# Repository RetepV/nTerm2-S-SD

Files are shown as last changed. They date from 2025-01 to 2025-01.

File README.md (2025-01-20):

# nTerm2-S-SD
My rendition of the uTerm2-S. In SMD, but easily solderable. In a slightly more usable form. As extra, it can switch between normal and cross (null-modem) in software.

This is a rendition of the nTerm2-S with extra PSRAM, a few extra I/O lines, and an SD card slot.

It is based on the FABGL library from Fabrizio Di Vittori.

THIS IS A WORK IN PROGESS! I.E. UNLESS STATED AS WORKING, IT DOES NOT WORK!

This design is available under GPL License V3. This means that I DO NOT release it for commercial use, unless with my explicit written and signed consent. Please contact me if you have commercial questions.

uTerm2-S: https://hackaday.io/project/181583-uterm2-s-a-multi-emulation-color-rs232-terminal
fabgl: http://www.fabglib.org/, https://github.com/fdivitto/FabGL

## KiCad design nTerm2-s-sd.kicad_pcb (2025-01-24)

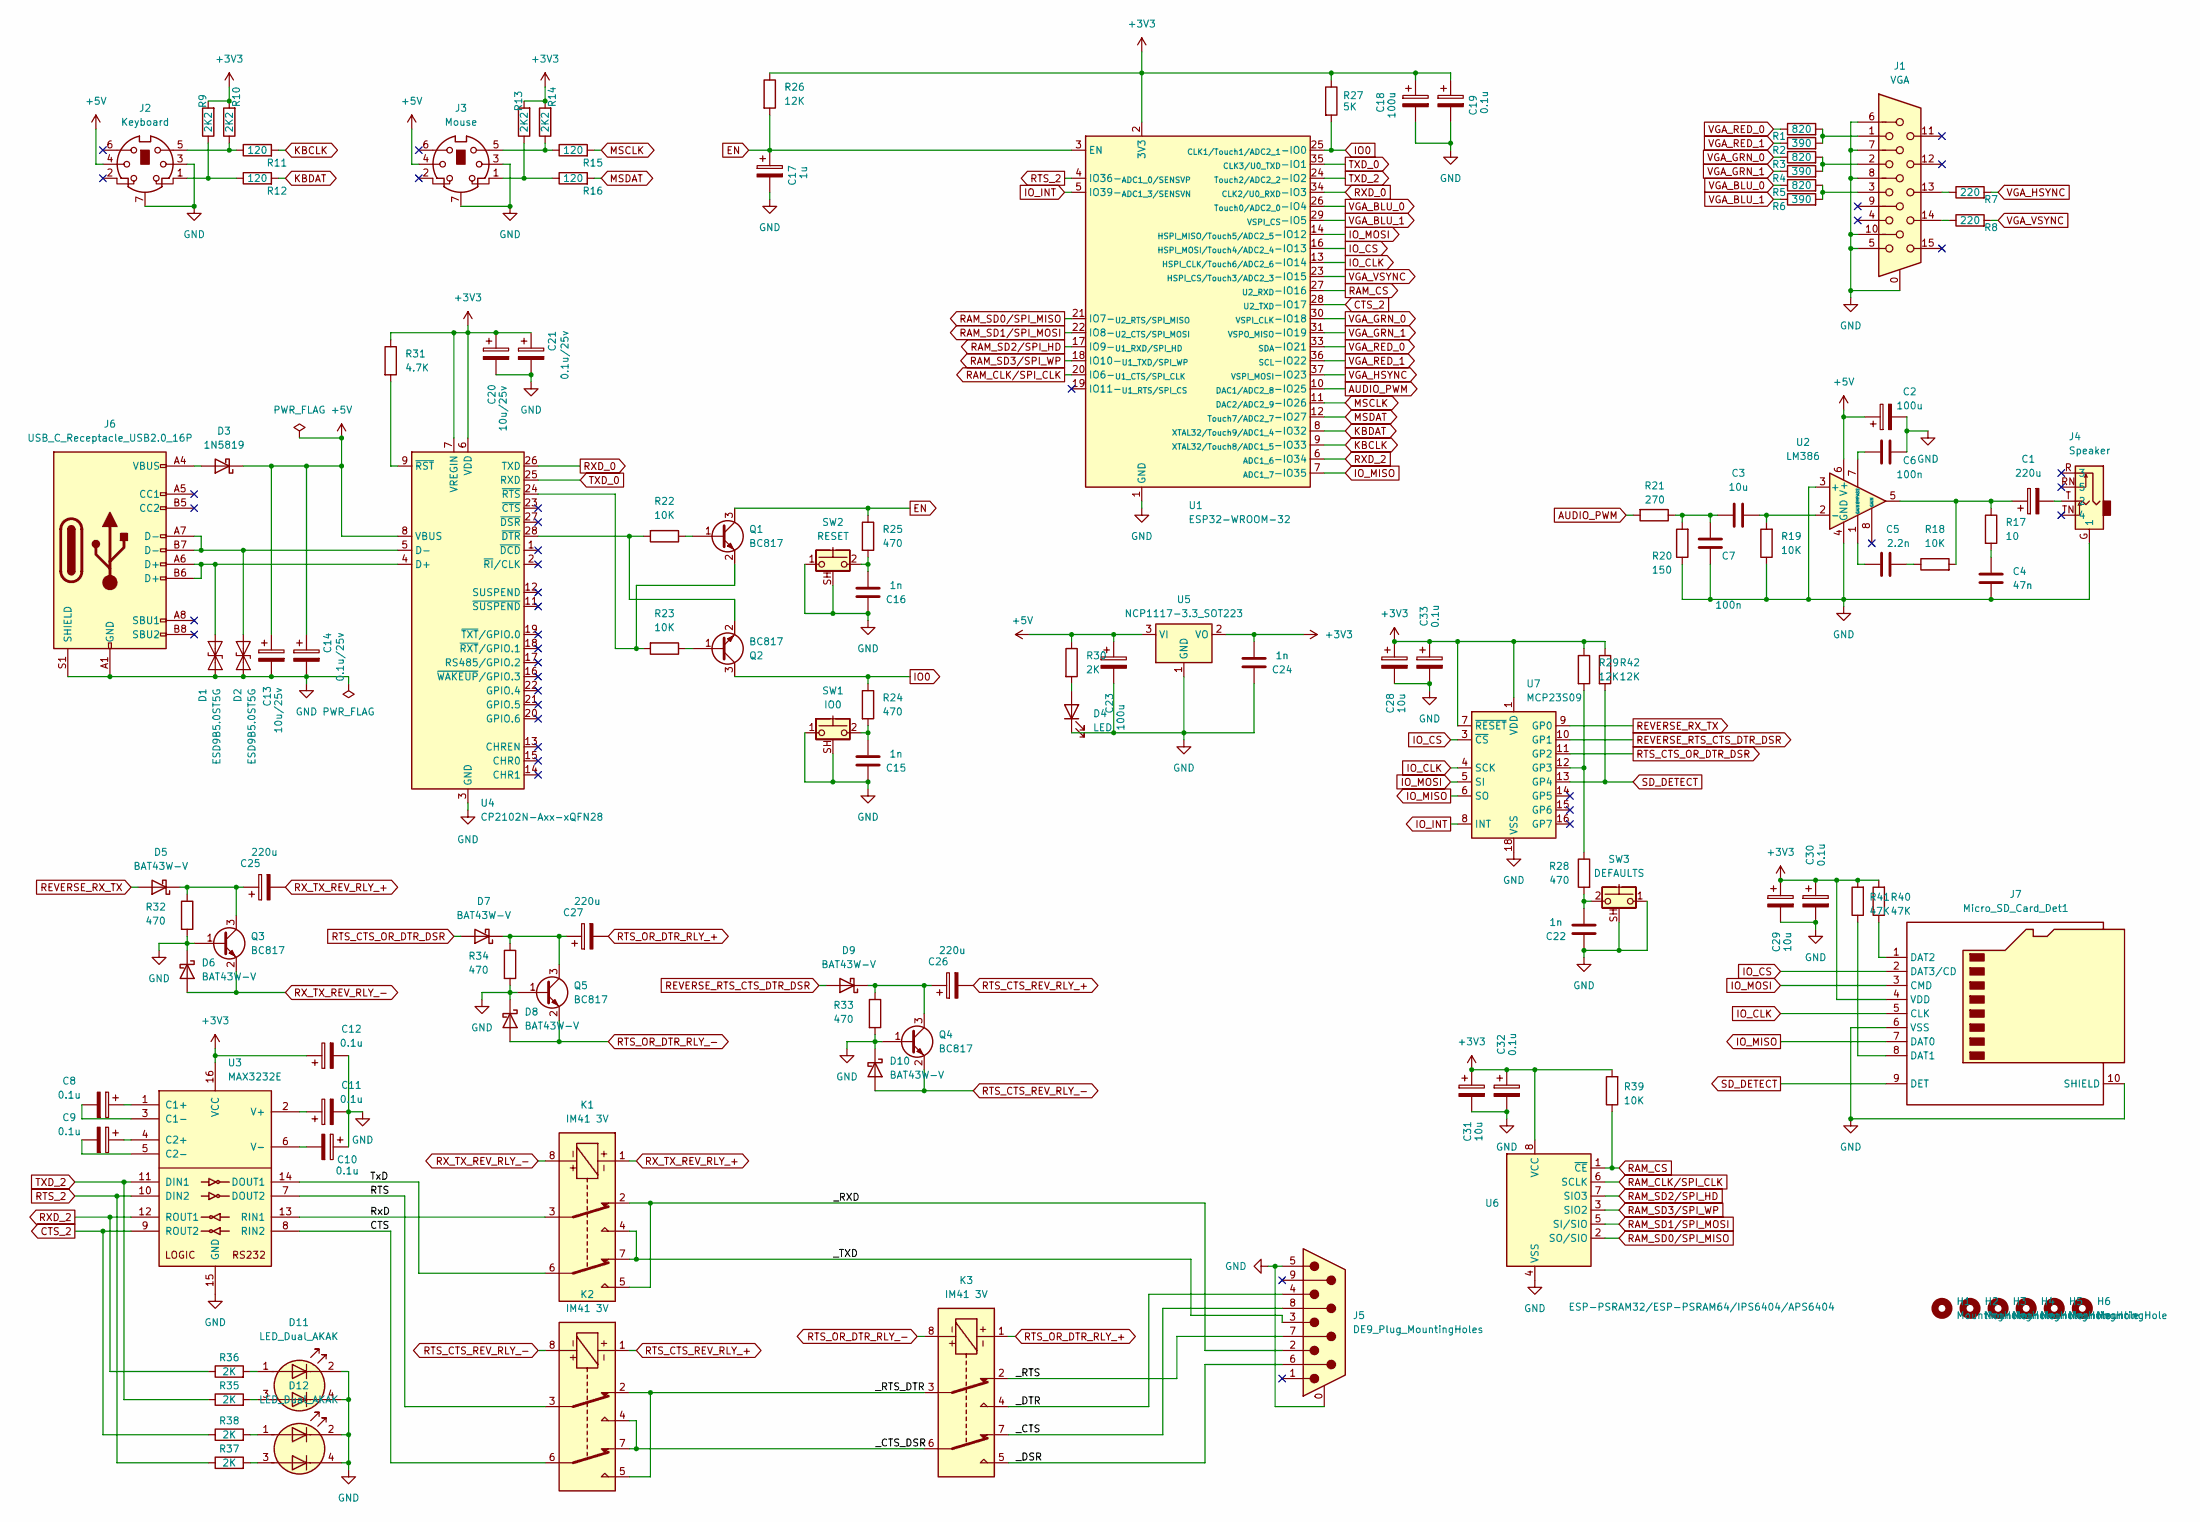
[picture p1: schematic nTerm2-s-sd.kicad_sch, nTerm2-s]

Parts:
C1: 220u; CP_Elec_6.3x7.7
C2: 100u; CP_Elec_6.3x7.7
C3: 10u; C_0805_2012Metric_Pad1.18x1.45mm_HandSolder
C4: 47n; C_0603_1608Metric_Pad1.08x0.95mm_HandSolder
C5: 2.2n; C_0603_1608Metric_Pad1.08x0.95mm_HandSolder
C6, C7: 100n; C_0603_1608Metric_Pad1.08x0.95mm_HandSolder
C8, C9, C10, C11, C12, C19, C30, C32, C33: 0.1u; CP_EIA-3216-18_Kemet-A_Pad1.58x1.35mm_HandSolder
C13, C20: 10u/25v; CP_EIA-3216-18_Kemet-A_Pad1.58x1.35mm_HandSolder
C14, C21: 0.1u/25v; CP_EIA-3216-18_Kemet-A_Pad1.58x1.35mm_HandSolder
C15, C16, C22, C24: 1n; C_0603_1608Metric_Pad1.08x0.95mm_HandSolder
C17: 1u; CP_EIA-3216-18_Kemet-A_Pad1.58x1.35mm_HandSolder
C18, C23: 100u; CP_EIA-3216-18_Kemet-A_Pad1.58x1.35mm_HandSolder
C25, C26, C27: 220u; CP_EIA-3216-18_Kemet-A_Pad1.58x1.35mm_HandSolder
C28, C29, C31: 10u; CP_EIA-3216-18_Kemet-A_Pad1.58x1.35mm_HandSolder
D1, D2: ESD9B5.0ST5G; D_SOD-923
D3: 1N5819; Nexperia_CFP3_SOD-123W
D4: LED; DIALIGHT_LED_3MM_SINGLE
D5, D6, D7, D8, D9, D10: BAT43W-V; D_SOD-123
D11, D12: LED_Dual_AKAK; DIALIGHT_LED_3MM_DOUBLE
H1, H2, H3, H4, H5, H6: MountingHole; MountingHole_3.2mm_M3
J1: VGA; DSUB-15-HD_Female_Horizontal_P2.29x1.98mm_EdgePinOffset8.35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
J2: Keyboard; Connector_Mini-DIN_Female_6Pin_2rows
J3: Mouse; Connector_Mini-DIN_Female_6Pin_2rows
J4: Speaker; Jack_3.5mm_Ledino_KB3SPRS_Horizontal
J5: DE9_Plug_MountingHoles; DSUB-9_Male_Horizontal_P2.77x2.84mm_EdgePinOffset4.94mm_Hou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
J6: USB_C_Receptacle_USB2.0_16P; USB_C_Receptacle_Molex_213716-0001
J7: Micro_SD_Card_Det1; GCT-MEM2055-00-190-01-A
K1, K2, K3: IM41 3V; Relay_DPDT_AXICOM_IMSeries_JLeg
Q1, Q2, Q3, Q4, Q5: BC817; SOT-23
R1, R3, R5: 820; R_0603_1608Metric_Pad0.98x0.95mm_HandSolder
R2, R4, R6: 390; R_0603_1608Metric_Pad0.98x0.95mm_HandSolder
R7, R8: 220; R_0603_1608Metric_Pad0.98x0.95mm_HandSolder
R9, R10, R13, R14: 2K2; R_0603_1608Metric_Pad0.98x0.95mm_HandSolder
R11, R12, R15, R16: 120; R_0603_1608Metric_Pad0.98x0.95mm_HandSolder
R17: 10; R_0603_1608Metric_Pad0.98x0.95mm_HandSolder
R18, R19, R22, R23, R39: 10K; R_0603_1608Metric_Pad0.98x0.95mm_HandSolder
R20: 150; R_0603_1608Metric_Pad0.98x0.95mm_HandSolder
R21: 270; R_0603_1608Metric_Pad0.98x0.95mm_HandSolder
R24, R25, R28, R32, R33, R34: 470; R_0603_1608Metric_Pad0.98x0.95mm_HandSolder
R26, R29, R42: 12K; R_0603_1608Metric_Pad0.98x0.95mm_HandSolder
R27: 5K; R_0603_1608Metric_Pad0.98x0.95mm_HandSolder
R30, R35, R36, R37, R38: 2K; R_0603_1608Metric_Pad0.98x0.95mm_HandSolder
R31: 4.7K; R_0603_1608Metric_Pad0.98x0.95mm_HandSolder
R40, R41: 47K; R_0603_1608Metric_Pad0.98x0.95mm_HandSolder
SW1: IO0; SW_Tactile_SPST_Angled_PTS645Vx58-2LFS
SW2: RESET; SW_Tactile_SPST_Angled_PTS645Vx58-2LFS
SW3: DEFAULTS; SW_Tactile_SPST_Angled_PTS645Vx58-2LFS
U1: ESP32-WROOM-32
U2: LM386; SOIC-8_3.9x4.9mm_P1.27mm
U3: MAX3232E; SOIC-16_3.9x9.9mm_P1.27mm
U4: CP2102N-Axx-xQFN28; QFN-28-1EP_5x5mm_P0.5mm_EP3.35x3.35mm
U5: NCP1117-3.3_SOT223; SOT-223-3_TabPin2
U6: ESP-PSRAM32/ESP-PSRAM64/IPS6404/APS6404; SOIC-8_3.9x4.9mm_P1.27mm
U7: MCP23S09; SOIC-18W_7.5x11.6mm_P1.27mm

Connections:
+3V3: C12.1, C18.1, C19.1, C20.1, C21.1, C24.1, C28.1, C29.1, C30.1, C31.1, C32.1, C33.1, J7.4 (VDD), R9.2, R10.2, R13.2, R14.2, R26.1, R27.1, R29.1, R31.1, R39.2, R40.2, R41.2, R42.1, U1.2 (3V3), U3.16 (VCC), U4.6 (VDD), U4.7 (VREGIN), U5.2 (VO), U6.8 (VCC), U7.1 (VDD), U7.7 (~RESET)
+5V: C2.1, C13.1, C14.1, C23.1, D3.1 (K), J2.4, J3.4, R30.1, U2.6 (V+), U4.8 (VBUS), U5.3 (VI)
/CTS: K2.6, U3.8 (RIN2)
/RTS: K2.3, U3.7 (DOUT2)
/RxD: K1.3, U3.13 (RIN1)
/TxD: K1.6, U3.14 (DOUT1)
/_CTS: J5.8, K3.7
/_CTS_DSR: K2.4, K2.7, K3.6
/_DSR: J5.6, K3.5
/_DTR: J5.4, K3.4
/_RTS: J5.7, K3.2
/_RTS_DTR: K2.2, K2.5, K3.3
/_RXD: J5.2, K1.2, K1.5
/_TXD: J5.3, K1.4, K1.7
AUDIO_PWM: R21.2, U1.10 (_{DAC1/ADC2_8}-IO25)
CTS_2: R38.1, U1.28 (_{U2_TXD}-IO17), U3.9 (ROUT2)
EN: C17.1, Q1.3 (C), R25.1, R26.2, U1.3 (EN)
GND: C2.2, C4.2, C6.2, C7.1, C10.1, C11.2, C12.2, C13.2, C14.2, C15.2, C16.2, C17.2, C18.2, C19.2, C20.2, C21.2, C22.2, C23.2, C24.2, C28.2, C29.2, C30.2, C31.2, C32.2, C33.2, D1.1 (A1), D2.1 (A1), D4.2 (K), D6.1 (K), D8.1 (K), D10.1 (K), D11.2 (K1), D11.4 (K2), D12.2 (K1), D12.4 (K2), J1.0, J1.5, J1.6, J1.7, J1.8, J1.10, J2.3, J2.7, J3.3, J3.7, J4.G (1), J5.0 (PAD), J5.5, J6.A1 (GND), J6.A12 (GND), J6.B1 (GND), J6.B12 (GND), J6.S1 (SHIELD), J7.6 (VSS), J7.10 (SHIELD), Q3.1 (B), Q4.1 (B), Q5.1 (B), R19.1, R20.1, R32.2, R33.2, R34.2, SW1.1, SW1.SH (B), SW2.1, SW2.SH (B), SW3.1, SW3.SH (B), U1.1 (GND), U1.15 (GND), U1.38 (GND), U1.39 (GND), U2.3 (+), U2.4 (GND), U3.15 (GND), U4.3 (GND), U4.29 (GND), U5.1 (GND), U6.4 (VSS), U7.18 (VSS)
IO0: Q2.3 (C), R24.1, R27.2, U1.25 (_{CLK1/Touch1/ADC2_1}-IO0)
IO_CLK: J7.5 (CLK), U1.13 (_{HSPI_CLK/Touch6/ADC2_6}-IO14), U7.4 (SCK)
IO_CS: J7.2 (DAT3/CD), U1.16 (_{HSPI_MOSI/Touch4/ADC2_4}-IO13), U7.3 (~CS)
IO_INT: U1.5 (IO39-_{ADC1_3/SENSVN}), U7.8 (INT)
IO_MISO: J7.7 (DAT0), U1.7 (_{ADC1_7}-IO35), U7.6 (SO)
IO_MOSI: J7.3 (CMD), U1.14 (_{HSPI_MISO/Touch5/ADC2_5}-IO12), U7.5 (SI)
KBCLK: R11.2, U1.9 (_{XTAL32/Touch8/ADC1_5}-IO33)
KBDAT: R12.2, U1.8 (_{XTAL32/Touch9/ADC1_4}-IO32)
MSCLK: R15.2, U1.11 (_{DAC2/ADC2_9}-IO26)
MSDAT: R16.2, U1.12 (_{Touch7/ADC2_7}-IO27)
unnamed: C1.1, R17.1, R18.2, U2.5
unnamed: C3.1, C7.2, R20.2, R21.1
unnamed: C4.1, R17.2
unnamed: C5.1, U2.1 (GAIN)
unnamed: C5.2, R18.1
unnamed: C15.1, R24.2, SW1.2
unnamed: C16.1, R25.2, SW2.2
unnamed: C22.1, R28.2, SW3.2
unnamed: D1.2 (A2), J6.A6 (D+), J6.B6 (D+), U4.4 (D+)
unnamed: D2.2 (A2), J6.A7 (D-), J6.B7 (D-), U4.5 (D-)
unnamed: D3.2 (A), J6.A4 (VBUS), J6.A9 (VBUS), J6.B4 (VBUS), J6.B9 (VBUS)
unnamed: D4.1 (A), R30.2
unnamed: C25.1, D5.1 (K), Q3.3 (C), R32.1
unnamed: C27.1, D7.1 (K), Q5.3 (C), R34.1
unnamed: C26.1, D9.1 (K), Q4.3 (C), R33.1
unnamed: D11.1 (A1), R36.2
unnamed: D11.3 (A2), R35.2
unnamed: D12.1 (A1), R38.2
unnamed: D12.3 (A2), R37.2
unnamed: J1.1, R1.2, R2.2
unnamed: J1.2, R3.2, R4.2
unnamed: J1.3, R5.2, R6.2
unnamed: J1.13, R7.1
unnamed: J1.14, R8.1
unnamed: J2.1, R9.1, R12.1
unnamed: J2.5, R10.1, R11.1
unnamed: J3.1, R13.1, R16.1
unnamed: J3.5, R14.1, R15.1
unnamed: C1.2, J4.T (2)
unnamed: J7.8 (DAT1), R41.1
unnamed: J7.1 (DAT2), R40.1
unnamed: Q1.1 (B), R22.1
unnamed: Q1.2 (E), R23.2, U4.24 (~RTS)
unnamed: Q2.1 (B), R23.1
unnamed: Q2.2 (E), R22.2, U4.28 (~DTR)
unnamed: C3.2, R19.2, U2.2 (-)
unnamed: C6.1, U2.7 (BYPASS)
unnamed: C8.1, U3.1 (C1+)
unnamed: C8.2, U3.3 (C1-)
unnamed: C9.1, U3.4 (C2+)
unnamed: C9.2, U3.5 (C2-)
unnamed: C11.1, U3.2 (V+)
unnamed: C10.2, U3.6 (V-)
unnamed: R31.2, U4.9 (~RST)
unnamed: R28.1, R29.2, U7.12 (GP3)
RAM_CLK/SPI_CLK: U1.20 (IO6-_{U1_CTS/SPI_CLK}), U6.6 (SCLK)
RAM_CS: R39.1, U1.27 (_{U2_RXD}-IO16), U6.1 (~CE)
RAM_SD0/SPI_MISO: U1.21 (IO7-_{U2_RTS/SPI_MISO}), U6.2 (SO/SIO)
RAM_SD1/SPI_MOSI: U1.22 (IO8-_{U2_CTS/SPI_MOSI}), U6.5 (SI/SIO)
RAM_SD2/SPI_HD: U1.17 (IO9-_{U1_RXD/SPI_HD}), U6.7 (SIO3)
RAM_SD3/SPI_WP: U1.18 (IO10-_{U1_TXD/SPI_WP}), U6.3 (SIO2)
REVERSE_RTS_CTS_DTR_DSR: D9.2 (A), U7.10 (GP1)
REVERSE_RX_TX: D5.2 (A), U7.9 (GP0)
RTS_2: R37.1, U1.4 (IO36-_{ADC1_0/SENSVP}), U3.10 (DIN2)
RTS_CTS_OR_DTR_DSR: D7.2 (A), U7.11 (GP2)
RTS_CTS_REV_RLY_+: C26.2, K2.1
RTS_CTS_REV_RLY_-: D10.2 (A), K2.8, Q4.2 (E)
RTS_OR_DTR_RLY_+: C27.2, K3.1
RTS_OR_DTR_RLY_-: D8.2 (A), K3.8, Q5.2 (E)
RXD_0: U1.34 (_{CLK2/U0_RXD}-IO3), U4.26 (TXD)
RXD_2: R36.1, U1.6 (_{ADC1_6}-IO34), U3.12 (ROUT1)
RX_TX_REV_RLY_+: C25.2, K1.1
RX_TX_REV_RLY_-: D6.2 (A), K1.8, Q3.2 (E)
SD_DETECT: J7.9 (DET), R42.2, U7.13 (GP4)
TXD_0: U1.35 (_{CLK3/U0_TXD}-IO1), U4.25 (RXD)
TXD_2: R35.1, U1.24 (_{Touch2/ADC2_2}-IO2), U3.11 (DIN1)
VGA_BLU_0: R5.1, U1.26 (_{Touch0/ADC2_0}-IO4)
VGA_BLU_1: R6.1, U1.29 (_{VSPI_CS}-IO5)
VGA_GRN_0: R3.1, U1.30 (_{VSPI_CLK}-IO18)
VGA_GRN_1: R4.1, U1.31 (_{VSPO_MISO}-IO19)
VGA_HSYNC: R7.2, U1.37 (_{VSPI_MOSI}-IO23)
VGA_RED_0: R1.1, U1.33 (_{SDA}-IO21)
VGA_RED_1: R2.1, U1.36 (_{SCL}-IO22)
VGA_VSYNC: R8.2, U1.23 (_{HSPI_CS/Touch3/ADC2_3}-IO15)

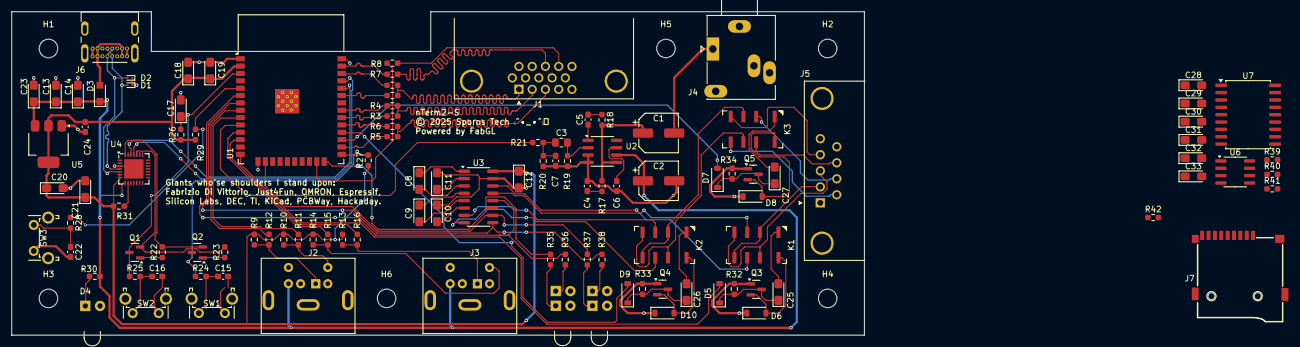
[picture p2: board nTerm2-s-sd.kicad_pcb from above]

Board: 2 copper layers, 147.3 x 55.9 mm, 118 parts (0 on the bottom side), 102 nets.

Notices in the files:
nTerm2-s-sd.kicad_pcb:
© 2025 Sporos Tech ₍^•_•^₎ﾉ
